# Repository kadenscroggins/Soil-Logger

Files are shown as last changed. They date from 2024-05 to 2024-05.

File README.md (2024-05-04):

# Soil-Logger
A couple of boards and a sensor cobbled together to log plant moisture to an SD card! In the future I plan on adding the ability for it to use the Wi-Fi functionalities of the ESP32 microcontroller to upload this data to a web server.

Component assembly

## Parts used
* [Adafruit ESP32-S3 Feather with 4MB Flash 2MB PSRAM - STEMMA QT / Qwiic](https://www.adafruit.com/product/5477)
    * [Lithium Ion Polymer Battery Ideal For Feathers - 3.7V 400mAh](https://www.adafruit.com/product/3898)
* [Adalogger FeatherWing - RTC + SD Add-on For All Feather Boards](https://www.adafruit.com/product/2922)
    * [512MB micro SD Memory Card](https://www.adafruit.com/product/5252)
    * [CR1220 12mm Diameter - 3V Lithium Coin Cell Battery - CR1220](https://www.adafruit.com/product/380)
    * [Header Kit for Feather - 12-pin and 16-pin Female Header Set](https://www.adafruit.com/product/2886)
* [Adafruit STEMMA Soil Sensor - I2C Capacitive Moisture Sensor - JST PH 2mm](https://www.adafruit.com/product/4026)
    * [4-pin JST PH to JST SH Cable - STEMMA to QT / Qwiic - 200mm long](https://www.adafruit.com/product/4424)

## Assembly
1. Solder the included male headers onto the ESP32-S3 feather board. The black plastic should be on the bottom of the board with the short ends going up into the board and the long end going down.
    * I used my Miniware TS80P soldering iron for all soldering on this project, which was perfect for these small boards.
2. Solder the female header kit onto the RTC featherwing board. The black plastic should be on the top of the board.
3. Insert the coin cell into the RTC featherwing board.
4. Solder the AD0 pads on the back of the STEMMA soil sensor together to increase the i2c address by one.
    * The default address of the soil sensor conflicts with the address of the battery monitor on the microcontroller
5. Sandwich the battery between the two boards - it should be a pretty snug fit, they are designed to accomodate the specific battery on the parts list. The cable should stick out just under the battery port on the top board. The battery can stay disconnected until assembly is done.
6. Push the male headers of the top board all the way into the female headers in the bottom board.
7. Connect the larger end (JST PH) of the 4-pin cable to the STEMMA soil sensor, and the smaller end (JST SH) to the port in the center of the top board.
8. Plug the top board into your computer and [install the CircuitPython firmware](https://learn.adafruit.com/adafruit-esp32-s3-feather/circuitpython) used by this project.
9. Copy the code.py and sd_card_functions.py files into the CIRCUITPYTHON drive that appears when plugging in the microcontroller, and install all libraries in the /lib folder.
    * adafruit_max1704x
    * adafruit_pcf8523
    * adafruit_seesaw
    * neopixel
10. Plug in the SD card to the bottom board

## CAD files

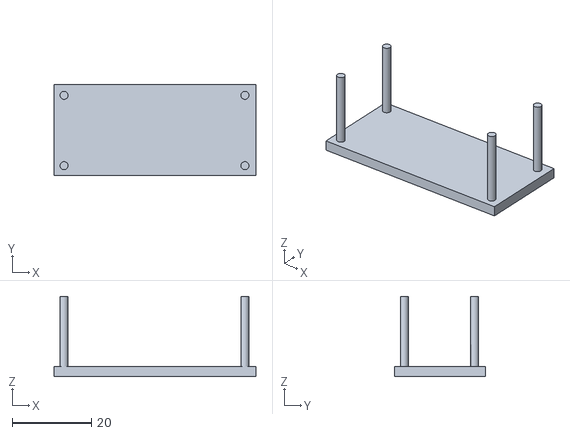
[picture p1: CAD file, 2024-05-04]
feather_assembly.stl
51.1 x 23.1 x 20.3

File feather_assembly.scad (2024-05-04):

in = 25.4; // Conv. to inches

board_width = 2 * in;
board_depth = 0.9 * in;
hole_rad = 0.05 * in;
hole_dist_edge = 0.1 * in;
hole_sep_depth = 0.7 * in;
hole_sep_width = 1.8 * in;

shell_thickness = 0.1 * in;
shell_gap = 0.01 * in;
peg_len = 0.8 * in;
peg_gap = 0.01 * in;

module peg(x,y,z) {
    translate([x,y,z]) {
        cylinder(
            h = peg_len,
            r = hole_rad - peg_gap,
            $fn = 90
        );
    }
}

union() {
    cube([
        board_width + shell_gap,
        board_depth + shell_gap,
        shell_thickness
    ]);

    peg(
        hole_dist_edge,
        hole_dist_edge,
        0
    );

    peg(
        hole_dist_edge,
        hole_dist_edge + hole_sep_depth,
        0
    );

    peg(
        hole_dist_edge + hole_sep_width,
        hole_dist_edge,
        0
    );

    peg(
        hole_dist_edge + hole_sep_width,
        hole_dist_edge + hole_sep_depth,
        0
    );
}

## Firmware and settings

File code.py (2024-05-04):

'''
i2c addresses:
    PCF8523 (RTC):      0x68 / 104
    MAX17048 (Batt):    0x36 /  54
    STEMMA soil sensor: 0x37 /  55
'''
import alarm
import board
import neopixel
import time
import traceback
from sd_card_functions import sd_mount_append_unmount as sd_write
from adafruit_max1704x import MAX17048
from adafruit_pcf8523 import PCF8523
from adafruit_seesaw.seesaw import Seesaw

# Weekdays for RTC
days = ("Sunday", "Monday", "Tuesday", "Wednesday", "Thursday", "Friday", "Saturday")

# Set up i2c
i2c = board.I2C()
while not i2c.try_lock():
    pass
i2c_address_list = i2c.scan()
i2c.unlock()

# Assign i2c devices
batt = MAX17048(i2c)
soil = Seesaw(board.STEMMA_I2C(), addr=0x37)
rtc = PCF8523(board.I2C())

# Set up NeoPixel
pixel = neopixel.NeoPixel(board.NEOPIXEL, 1)
pixel.brightness = 0.05
pixel.fill((0, 255, 0))

# Collect timestamp
t = rtc.datetime
timestamp = f'[{t.tm_mon:02d}/{t.tm_mday:02d}/{t.tm_year:04d}-' + \
            f'{t.tm_hour:02d}:{t.tm_min:02d}:{t.tm_sec:02d}]'

# Collect battery info
batt_info = f'[{batt.cell_percent:.2f}% / {batt.cell_voltage:.1f}V]'

# Collect soil info
soil_temp_f = (soil.get_temp() * 1.8) + 32.0
soil_info = f'[{soil_temp_f:.2f}F {soil.moisture_read()}]'

print(f'Logging: {timestamp}{batt_info}{soil_info}')

try:
    sd_write(
        "soil_log.txt",
        f'\n{timestamp}{batt_info}{soil_info}',
        "Timestamp, Battery Info, Soil Info"
    )
except Exception as e:
    print("\nError reading SD card!\n")
    traceback.print_exception(e)
    print()
    for _ in range(4):
        pixel.fill((255, 0, 0))
        time.sleep(0.1)
        pixel.fill((0, 0, 0))
        time.sleep(0.1)

print("Sleepy time!")
time_alarm = alarm.time.TimeAlarm(monotonic_time=time.monotonic() + 20)
alarm.exit_and_deep_sleep_until_alarms(time_alarm)

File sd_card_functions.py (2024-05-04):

import board
import sdcardio
import storage
import os

def sd_mount_append_unmount(filename: str, data: str, header: str):
    try:
        spi = board.SPI()
        cs = board.D10
        sdcard = sdcardio.SDCard(spi, cs)
        vfs = storage.VfsFat(sdcard)
        storage.mount(vfs, "/sd")

        try:
            os.stat("/sd/%s" % filename)
        except Exception as _:
            with open(file="/sd/%s" % filename, mode="w", encoding="utf-8") as f:
                f.write(header)

        with open(file="/sd/%s" % filename, mode="a", encoding="utf-8") as f:
            f.write(data)

        storage.umount("/sd")
    except Exception as _:
        raise
    finally:
        sdcard.deinit()
        spi.deinit()
